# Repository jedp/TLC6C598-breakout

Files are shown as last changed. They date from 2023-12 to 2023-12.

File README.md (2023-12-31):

# TLC6C598 Shift register / LED driver breakout board

The correct timing can be achieved with SPI polarity=0, phase=0. In CubeMX,
this corresponds to CPOL=Low, CPHA=1 edge.

/CLS can be tied high.

Timing Diagram

After shifting in data, you have to manually raise and lower a GPIO to act as a
register clock to cause the TLC to transfer that data to the storage registers
for display, which is done on the rising edge of RCK.

Since the high time of the register clock is the same as the serial clock, you
can achieve this by pulling the clock GPIO low before transmitting data and
then pulling it high when you're done.

```
	// Register clock low.
	HAL_GPIO_WritePin(GPIOA, GPIO_RCK, GPIO_PIN_RESET);
	
	// Shift data ...
	HAL_SPI_Transmit(&hspi1, (uint8_t*) data, 1, 1);

	// Register clock high: See the blinkies.
	HAL_GPIO_WritePin(GPIOA, GPIO_RCK, GPIO_PIN_SET);
```

PCB Image

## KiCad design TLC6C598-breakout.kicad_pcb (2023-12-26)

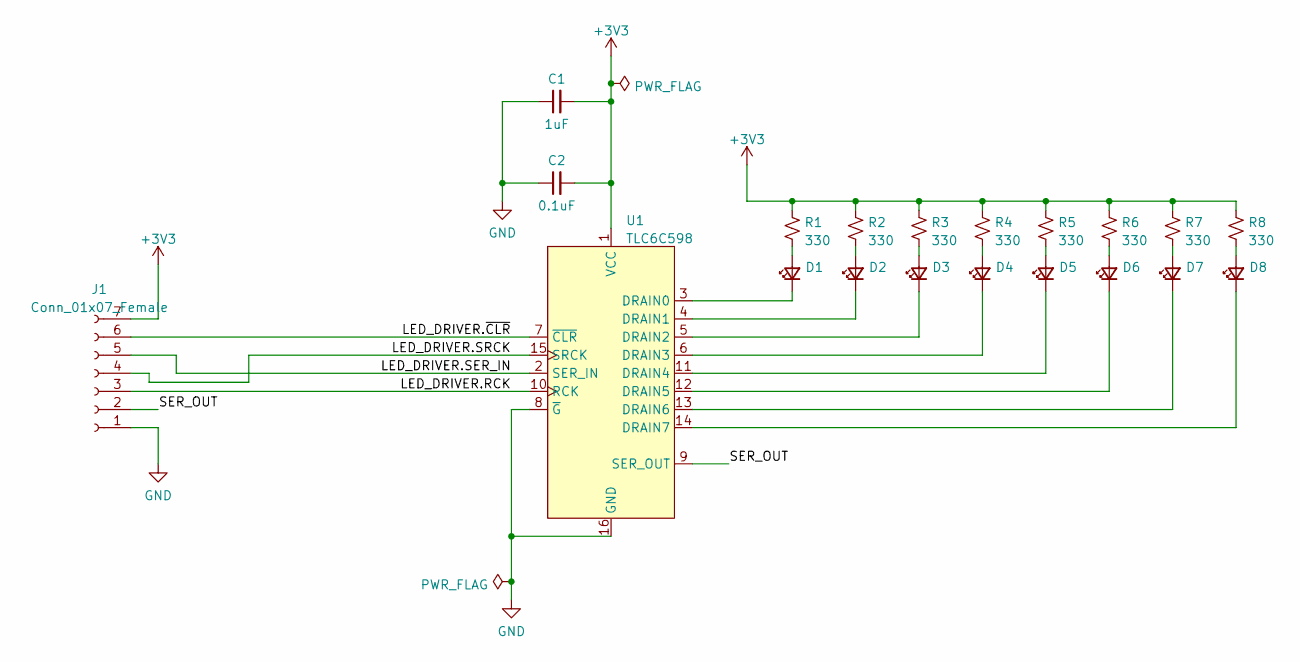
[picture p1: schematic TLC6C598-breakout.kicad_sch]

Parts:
C1: 1uF; C_0805_2012Metric
C2: 0.1uF; C_0603_1608Metric
D1, D2, D3, D4, D5, D6, D7, D8: LED_Small; LED_0603_1608Metric
J1: Conn_01x07_Female; PinHeader_1x07_P2.54mm_Vertical
R1, R2, R3, R4, R5, R6, R7, R8: 330; R_0603_1608Metric
U1: TLC6C598; TSSOP-16-1EP_4.4x5mm_P0.65mm_EP3x3mm_ThermalVias

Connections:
+3V3: C1.2, C2.2, J1.7, R1.1, R2.1, R3.1, R4.1, R5.1, R6.1, R7.1, R8.1, U1.1 (VCC)
/LED_DRIVER.RCK: J1.3, U1.10 (RCK)
/LED_DRIVER.SER_IN: J1.5, U1.2 (SER_IN)
/LED_DRIVER.SRCK: J1.4, U1.15 (SRCK)
/LED_DRIVER.~CLR: J1.6, U1.7 (~CLR)
/SER_OUT: J1.2, U1.9 (SER_OUT)
GND: C1.1, C2.1, J1.1, U1.8 (~G), U1.16 (GND)
unnamed: D1.1 (K), U1.3 (DRAIN0)
unnamed: D1.2 (A), R1.2
unnamed: D2.1 (K), U1.4 (DRAIN1)
unnamed: D2.2 (A), R2.2
unnamed: D3.1 (K), U1.5 (DRAIN2)
unnamed: D3.2 (A), R3.2
unnamed: D4.1 (K), U1.6 (DRAIN3)
unnamed: D4.2 (A), R4.2
unnamed: D5.1 (K), U1.11 (DRAIN4)
unnamed: D5.2 (A), R5.2
unnamed: D6.1 (K), U1.12 (DRAIN5)
unnamed: D6.2 (A), R6.2
unnamed: D7.1 (K), U1.13 (DRAIN6)
unnamed: D7.2 (A), R7.2
unnamed: D8.1 (K), U1.14 (DRAIN7)
unnamed: D8.2 (A), R8.2

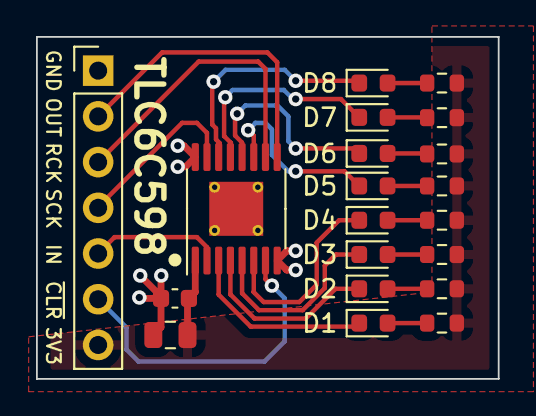
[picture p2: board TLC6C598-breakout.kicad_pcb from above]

Board: 2 copper layers, 25.7 x 19.0 mm, 20 parts (0 on the bottom side), 23 nets.

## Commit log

2023-12-26 TLC6C598 breakout board
    [TLC6C598-breakout.kicad_pcb, TLC6C598-breakout.kicad_sch]
2023-12-26 PCB image
2023-12-31 Document SPI implementation
